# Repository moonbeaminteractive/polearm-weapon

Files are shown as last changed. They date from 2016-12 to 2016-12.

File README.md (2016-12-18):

# polearm-weapon
pole rod staff based weapon for short range area events

##Concept: 
Wand/rod is a weapon which can cast three different kinds of spells by sending sound signals to the vest. The kind of spell is visualized by the led strip on the wand. There will be deplay between each spell, and the delay time can be shortened by one of the pickups. In order to cast a spell, the player has to both swing the rod to activate it and push one of the three buttons to cast a specific type of spell. 

##Software: 

Prerequisite libraries:  <br/>
Statistic.h  <br/>
Adafruit_DotStar.h <br/>

Statistic.h: calculates the swing variance of the gyro sensor  <br/>
Adafruit_DotStar.h: controls the RGB lighting on the led strip  <br/>

The software continuously polls the 3 rod buttons (red, green, blue) to select a spell. <br/>
Also, it continuously logs ADXL accelerometer data in blocks of 100 values and calculates the variance of the samples. Using the variance instead of the raw values allows the tracking of rapid wand motions to cast a spell, no matter what the initial direction of the wand is. <br/>

When casting each spell, the DotStar LEDs light up with the respective color (blue for the blue button, red for the red button, green for the green button) to conveniently visualize which spell has been selected. Additional functionality is implemented to drive a buzzer with a frequency that depends on the spell that is casted. For the red spell, a buzzer tone with period of 100 ms is generated, for the green a tone with 200 ms period is generated, and for the blue a tone with 300 ms period is generated. <br/>

Time-sensitive functions of the code have been implemented with the millis() function to avoid blocking that the delay() function introduces. <br/>

##Usage Settings:
Current settings:<br/>
Default blockout - 30 seconds (slow recharge)<br/>
Blockout with pickup - 10 seconds (faster boosted recharge)<br/>

When a weapon booster pickup is correctly attached, the wand flashes 5 times to notify the user that it has detected and activated it. The wand glows a default yellow color when active, and whenever a spell is castable. If it is timed out, on blockout after casting a spell, all lights on the wand will switch off until it is recharged again. On casting a spell, the wand glows the same color as the spell.<br/>

To use, plug in a USB-A to USB-B connector between the wand and the vest.<br/>

##Hardware: 
1 x gyro sensor <br/>
1 x magnetic buzzer <br/>
1 x dotstar led strip <br/>
1 x arduino mini <br/>
3 x push button <br/>
1 x USB-B <br/>

Gyro sensor: detects if the rod is activated or not. Player will swing the rod to activate the weapon <br/>
Magnetic buzzer: sends sound signal to receivers installed on vests <br/>
Dotstar led strip: displays which spell just casted by the player (r, g, b) <br/>
Push button: each color of the push button (r, g, b) will send a different kind of spells <br/>
USB-B: receives serial information from the vest for shorter spell recharge delay <br/>

##Circuit and PCB Design Process: 
We started with a very simple board – an Arduino Uno, an infrared emitter, a push button and a led strip. Then we improved it by adding more components and functionalities to the board – we added a tilt sensor switch for activation, a 6 degree of freedom sensor, a Piezo buzzer for casting different spells, a nrf24l01 for Bluetooth communication, and replaced the Arduino Uno with Arduino Pro Mini. In the next phase, we replaced the 6 degree of freedom sensor with a gyro sensor and removed the tilt switch as we decided to only use swing behavior to activate the wand, which could be achieved by just using the gyro sensor. We also added three kinds of buttons, imaging the player can perform different kinds of combinations of buttons for different spells. Then we moved on to the communication with the other parts. We realized that it would work the best if we communicated with the vest directly using serial via TX/RX pins instead of Bluetooth. Finally, the design we have right now has a USB-B for serial communication with the vest, removing the Bluetooth module. 

In order to fit the PCB into the wand, we wanted to limit its width to around 3.5 cm. We decided to put the gyro sensor and buzzer at the top of the wand for more accurate measurement. The initial PCB design was just about 3.6 cm. Matt helped us to produce the final design, which used the small resistor and a more compact layout to reduce the width to 3.4 cm. It also added two transistors for 5.0 V power supply. These tiny resistors and transistors saved lots of space for PCB design.

###Circuit
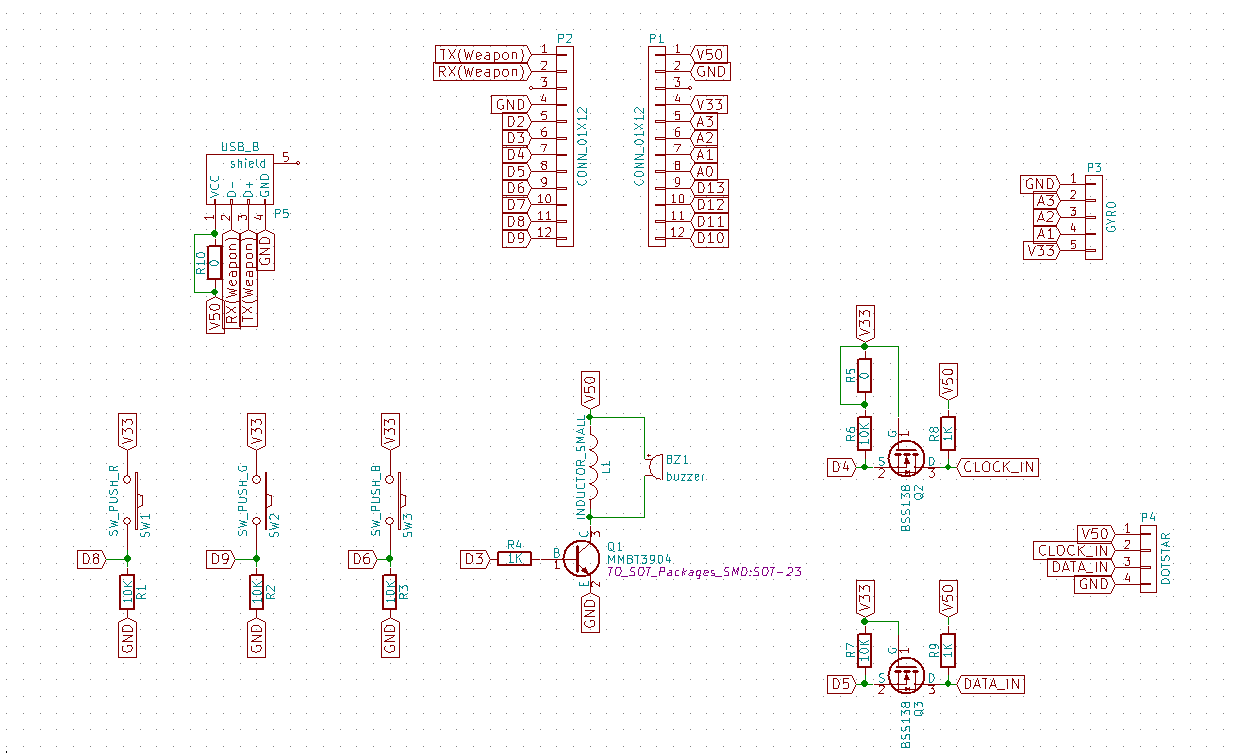
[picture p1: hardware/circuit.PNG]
Circuit
  

###PCB
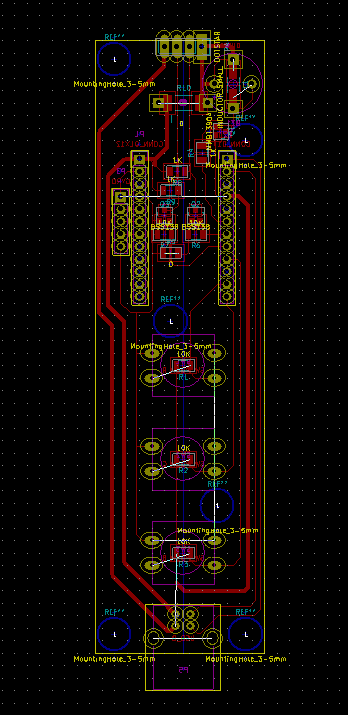
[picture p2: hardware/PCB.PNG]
PCB
  

###Fabrication Design: 
The design of weapon was in lowpoly style and we have a good rationale for the design.

The sytle of the design is futuristic overall and lowpoly design fits in the game.
Using lowpoly design, we are able to build three-dimensional objects by two dimensional materials like paper by folding them. In this way, we are able to put whatever electronics and PCB boards into it without destroying the idea of the weapon being a wand.
The design was generated by sketching, modelling and finally drawings. The tools used were Illustrator, Rhino and special thanks to Clement, whose tools helped with generating joints for the design.

As for the prototyping, We laser cut (using Epilog Mini Laser Cutter) the design using chipboard.

For the materials, we hesitated between plastic, yupo paper, chipboard as well as metal. Eventually, due to cost, the feasibility of laser cutting as well as the imagined final demonstration, we decided to have black chipboards serving as surfaces.

The output of laser film printer appears some errors because of mechanical manufacture and different settings of power and speed. The drawings were drawn in both AutoCAD and Illustrator. Dimensions in drawings were decided by both measurements and repetitive trail and error.

A challenge we encountered was to fit in the PCB boards and placing buttons, electronics at the right position, which wasted a lot of trails and time.

Deciding settings of power and speed was another challenge for us. Although each material corresponds to its suggested settings, materials produced by different manufacturers perform differently under the same setting. We kept adjusting the settings to cut through acrylic sheets but at the same time prevent it from melting and blackening. The final prototype was actually our fifth version of printing..
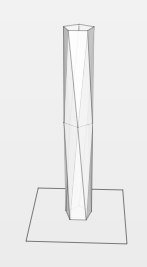
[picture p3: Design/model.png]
Design


###Paper Prototype:
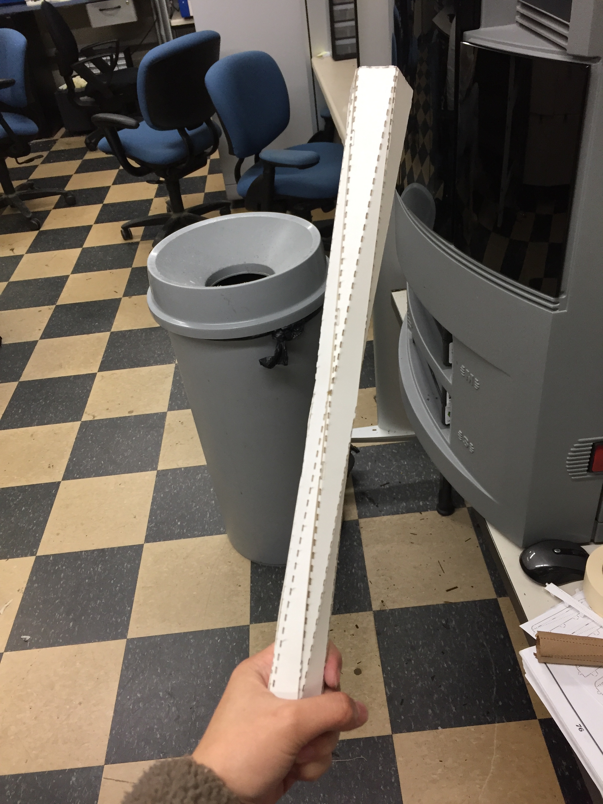
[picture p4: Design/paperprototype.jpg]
Paper
  

###Final Wand: 
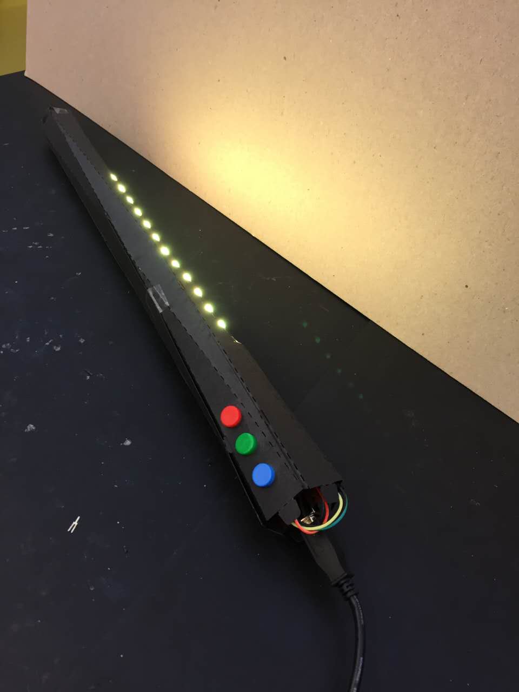
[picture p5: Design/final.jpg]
Wand


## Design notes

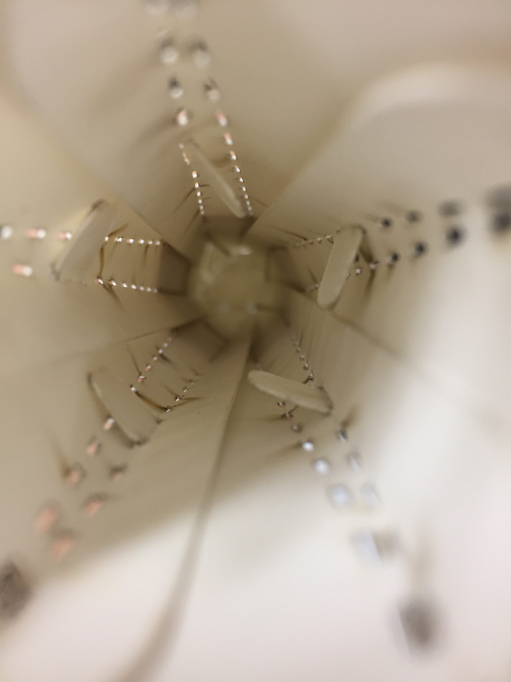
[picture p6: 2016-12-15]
Design/inside.jpg

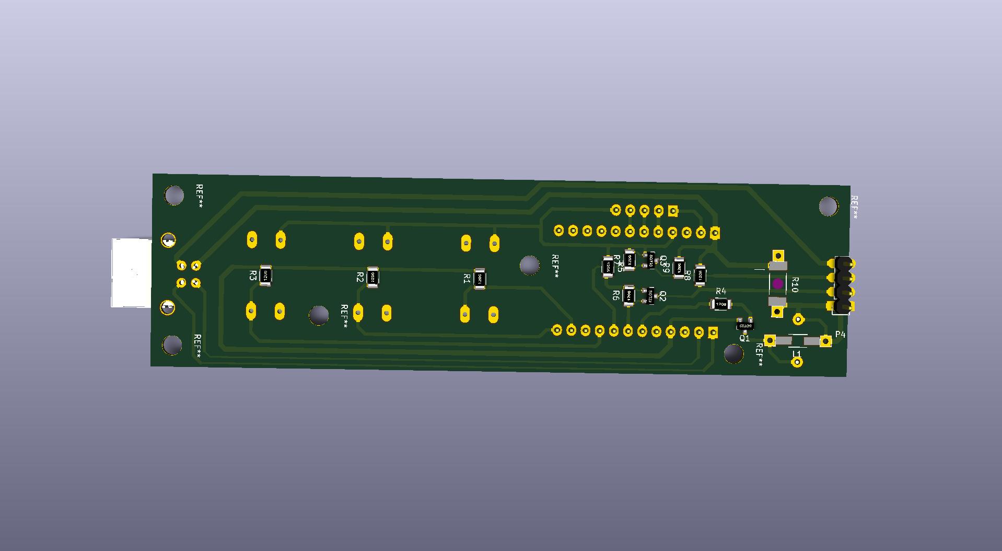
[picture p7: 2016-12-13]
hardware/rod-layout-2.jpg

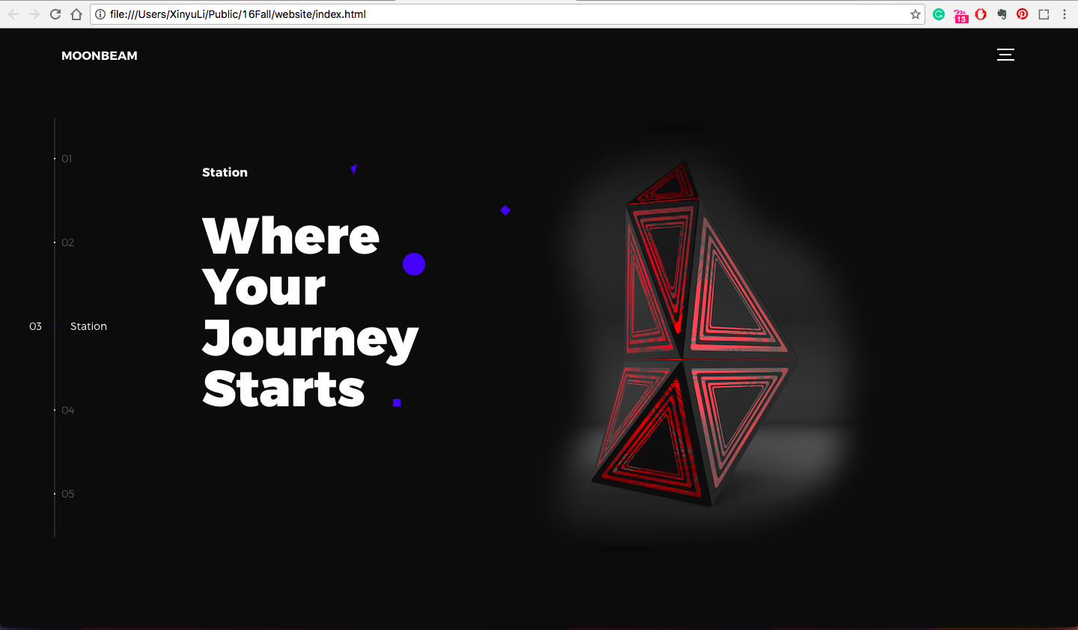
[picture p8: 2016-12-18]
Design/Screen Shot 2016-12-15 at 12.27.38 PM.png

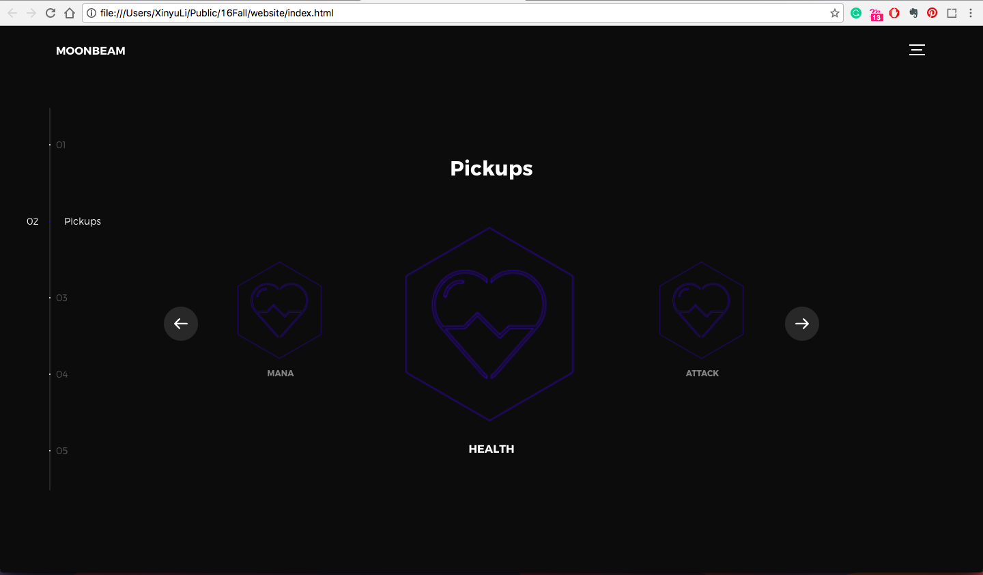
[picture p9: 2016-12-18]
Design/Screen Shot 2016-12-15 at 12.27.31 PM.png

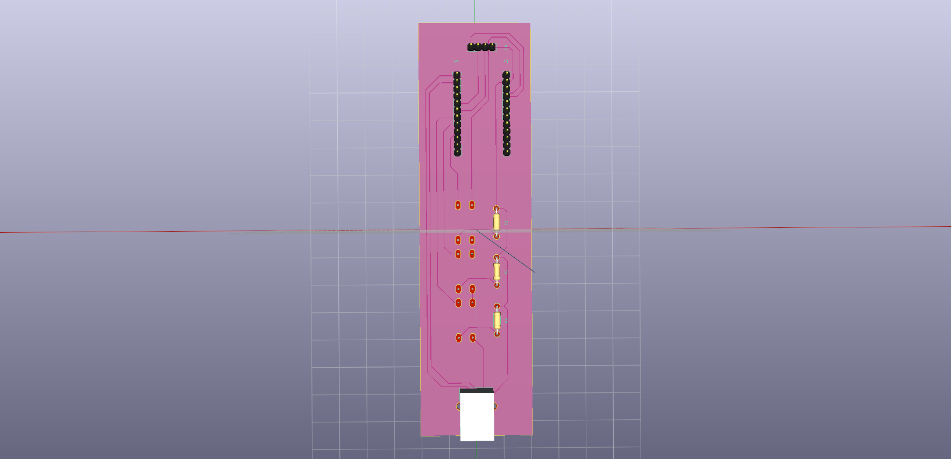
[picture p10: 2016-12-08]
hardware/rod.png

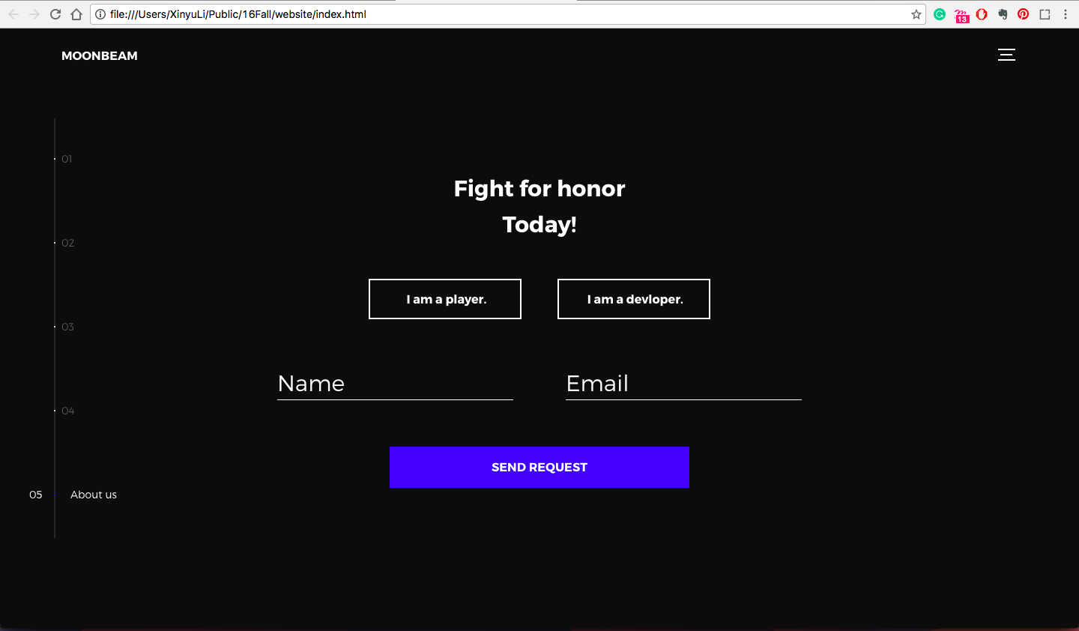
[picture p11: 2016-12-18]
Design/Screen Shot 2016-12-15 at 12.27.44 PM.png

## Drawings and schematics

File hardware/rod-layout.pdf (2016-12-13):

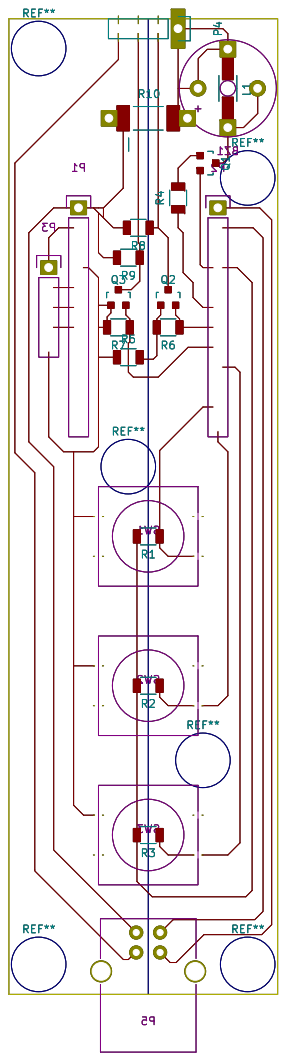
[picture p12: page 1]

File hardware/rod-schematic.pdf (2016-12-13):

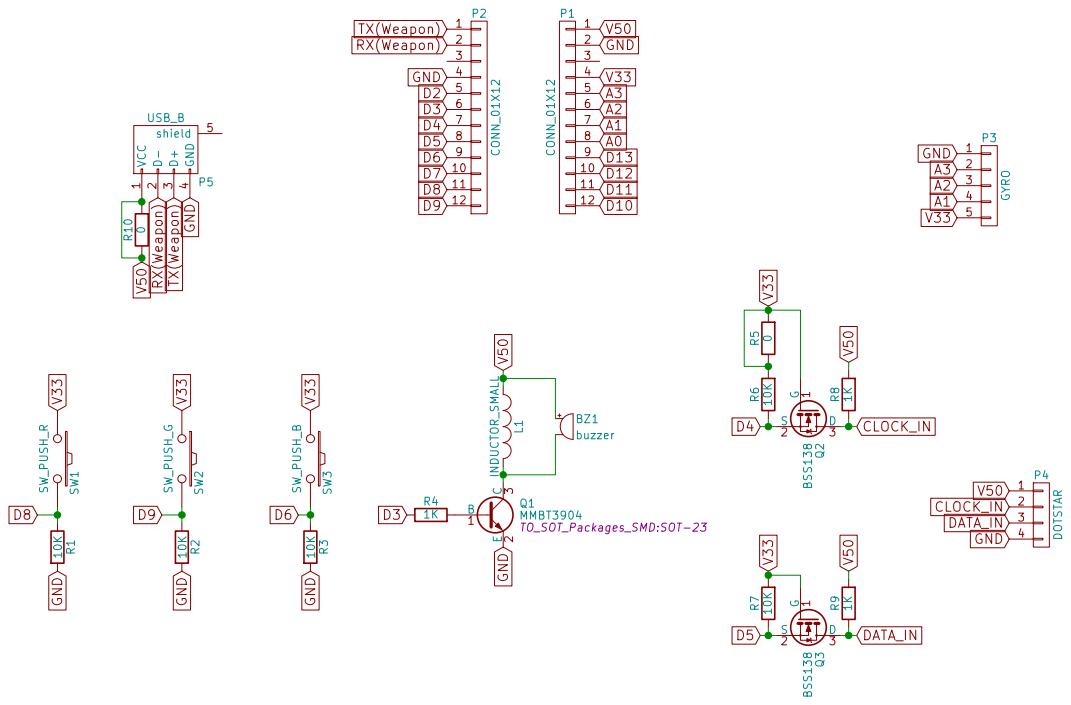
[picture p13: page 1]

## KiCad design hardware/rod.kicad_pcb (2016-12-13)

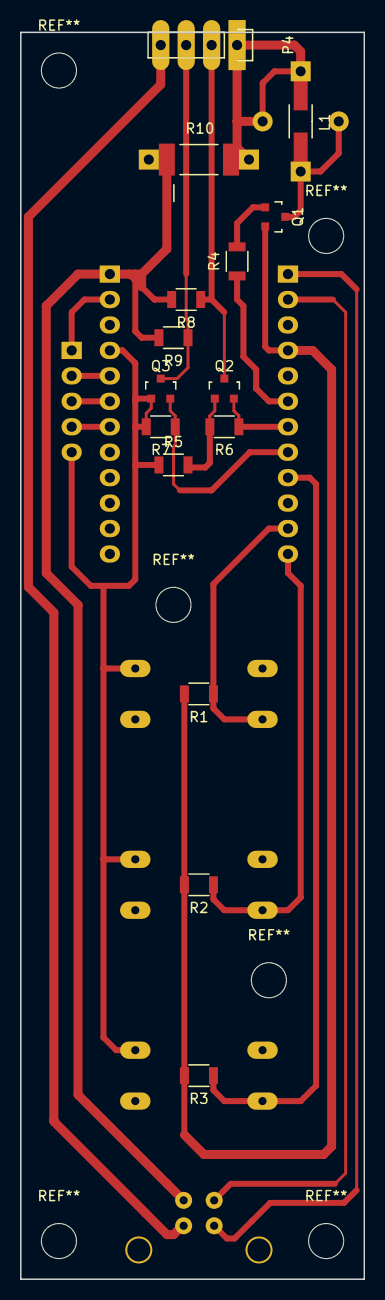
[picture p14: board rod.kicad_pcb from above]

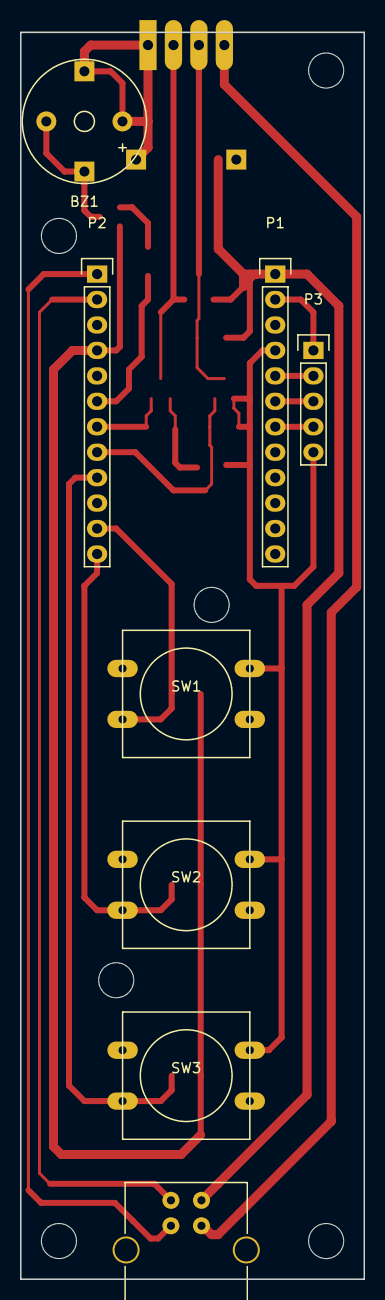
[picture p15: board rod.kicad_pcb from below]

Board: 2 copper layers, 34.3 x 124.5 mm, 23 parts (8 on the bottom side), 18 nets.

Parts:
BZ1: buzzer; Buzzer_12x9.5RM7.6
L1: INDUCTOR_SMALL; Resistor_SMD+THTuniversal_1206_RM10_HandSoldering
P1, P2: CONN_01X12; Pin_Header_Straight_1x12
P3: GYRO; Pin_Header_Straight_1x05
P4: DOTSTAR; Pin_Header_Straight_1x04
P5: USB_B
Q1: MMBT3904; SOT-23
Q2, Q3: BSS138; SOT-23
R1, R2, R3, R6, R7: 10K; R_1206
R4, R8, R9: 1K; R_1206
R5: 0; R_1206
R10: 0; Resistor_SMD+THTuniversal_2512_RM10_HandSoldering
SW1: SW_PUSH_R; SW_PUSH-12mm
SW2: SW_PUSH_G; SW_PUSH-12mm
SW3: SW_PUSH_B; SW_PUSH-12mm

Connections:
A1: P1.7, P3.4
A2: P1.6, P3.3
A3: P1.5, P3.2
CLOCK_IN: P4.2, Q2.3, R8.1
D3: P2.6, R4.1
D4: P2.7, Q2.2, R6.1
D5: P2.8, Q3.2, R7.1
D6: P2.9, R3.1, SW3.2
D8: P2.11, R1.1, SW1.2
D9: P2.12, R2.1, SW2.2
DATA_IN: P4.3, Q3.3, R9.1
GND: P1.2, P2.4, P3.1, P4.4, P5.4, Q1.2, R1.2, R2.2, R3.2
unnamed: BZ1.2, L1.2, Q1.3
unnamed: Q1.1, R4.2
RX(Weapon): P2.2, P5.2
TX(Weapon): P2.1, P5.3
V33: P1.4, P3.5, Q2.1, Q3.1, R5.1, R5.2, R6.2, R7.2, SW1.1, SW2.1, SW3.1
V50: BZ1.1, L1.1, P1.1, P4.1, P5.1, R8.2, R9.2, R10.1, R10.2

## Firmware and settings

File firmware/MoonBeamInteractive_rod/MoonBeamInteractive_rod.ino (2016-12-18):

#include <Arduino.h>
#include "Statistic.h"
#include <Adafruit_DotStar.h>
// Because conditional #includes don't work w/Arduino sketches...
#include <SPI.h>         // COMMENT OUT THIS LINE FOR GEMMA OR TRINKET



/////////// PUSHBUTTONS, LEDS, BUZZERS ///////////

const int buttonPin_green = 9;
const int buttonPin_blue = 6;
const int buttonPin_red = 8;

const int ledPin = 13;

const int buzzerPin = 3;              // buzzer positive pin


/////////// ADXL ///////////

Statistic xStats;

// these constants describe the pins. They won't change:
const int ADXL_xpin = A3;                  // x-axis of the accelerometer
const int ADXL_ypin = A2;                  // y-axis
const int ADXL_zpin = A1;                  // z-axis (only on 3-axis models)

#define ADXL_N_VALUES   100               // number of ADXL values for statistics
#define ADXL_STDEV_THRESHOLD  50          // sigma threshold for accelerometer


/////////// DOTSTAR ///////////

#define DOTSTAR_NUMPIXELS  13 // Number of LEDs in strip
#define DOTSTAR_NUMPIXELS_ON  13      // Number of LEDs to be actually used
#define DOTSTAR_NUMPIXELS_MANA  10   // Number of LEDs for Mana

#define DOTSTAR_DELAY_MS  500

#define DOTSTAR_DATAPIN    5
#define DOTSTAR_CLOCKPIN   4

Adafruit_DotStar strip = Adafruit_DotStar(
                           DOTSTAR_NUMPIXELS, DOTSTAR_DATAPIN, DOTSTAR_CLOCKPIN, DOTSTAR_BRG);
// The last parameter is optional -- this is the color data order of the
// DotStar strip, which has changed over time in different production runs.
// Your code just uses R,G,B colors, the library then reassigns as needed.
// Default is DOTSTAR_BRG, so change this if you have an earlier strip.

// Hardware SPI is a little faster, but must be wired to specific pins
// (Arduino Uno = pin 11 for data, 13 for clock, other boards are different).
//Adafruit_DotStar strip = Adafruit_DotStar(NUMPIXELS, DOTSTAR_BRG);


#define DOTSTAR_COLOR_BLUE  0x0000FF
#define DOTSTAR_COLOR_RED  0x00FF00
#define DOTSTAR_COLOR_GREEN  0xFF0000
#define DOTSTAR_COLOR_YELLOW  0xFFFF00
#define DOTSTAR_COLOR_BLANK  0x000000


// SPELLS state
#define NO_SPELL     0  //default
#define SPELL_RED    1  //indices
#define SPELL_GREEN  2
#define SPELL_BLUE   3
int spell_to_apply = 0;

//SPELL DELAY TIMER
#define DEFAULT_BLOCKOUT 30000  //30 seconds
#define BOOSTED_BLOCKOUT 10000
unsigned long set_blockout_time;    //TODO: MAKE THIS 20 OR 30 SECONDS LATER. OR MAYBE EVEN A MINUTE

boolean spell_castable = true;
unsigned long blockout_start_time = 0;

//PICKUPS
boolean pickup_present = true;
#define RECHARGE_AMMO_INDEX 0       //pre decided ammo bit from the string broadcasted by the vest
boolean prev_pickup_present = false;

void setup() {
  // initialize the serial communications:
  Serial.begin(9600);
  
 // while (!Serial) {
 //   ; // wait for serial port to connect. Needed for native USB port only
 // }

  // Recharge spells

  set_blockout_time = DEFAULT_BLOCKOUT;

  /////////// PUSHBUTTONS, LEDS, BUZZERS ///////////

  pinMode(buttonPin_green, INPUT);
  pinMode(buttonPin_blue, INPUT);
  pinMode(buttonPin_red, INPUT);

  pinMode(ledPin, OUTPUT);
  pinMode(buzzerPin, OUTPUT);

  //pinMode(testPin, OUTPUT);
  //digitalWrite(testPin, HIGH);

  /////////// ADXL ///////////
  xStats.clear(); //explicitly start clean

  /////////// DOTSTAR ///////////

#if defined(__AVR_ATtiny85__) && (F_CPU == 16000000L)
  clock_prescale_set(clock_div_1); // Enable 16 MHz on Trinket
#endif

  strip.begin(); // Initialize pins for output
  strip.show();  // Turn all LEDs off ASAP


  DOTSTAR_INIT();

}



void loop() {

 ///////// RECEIVE PICKUP FROM VEST ////////
 if (Serial.available())
    {
        String incomingString = Serial.readString();
        if (incomingString.length()>0) //this can be anything coming from the vest
        { 
               Serial.print("I received: ");
               Serial.println(incomingString);
               char bitOfInterest = incomingString[RECHARGE_AMMO_INDEX];  //change this later, maybe
               
               if(bitOfInterest=='1')
               {
                  pickup_present = true;
                  //Serial.print("bit of interest = 1");
               }
               else
               {
                  pickup_present = false;
                  //Serial.print("bit of interest = 0");
               }
         }
        setBlockoutTime(pickup_present);
  }


  /////////// PUSHBUTTONS ///////////
  
  int button_reading_green = digitalRead(buttonPin_green);
  int button_reading_blue = digitalRead(buttonPin_blue);
  int button_reading_red = digitalRead(buttonPin_red);


  if (button_reading_red) {
    spell_to_apply = SPELL_RED;
    //tone(5,10000);
  }
  else if (button_reading_green) {
    spell_to_apply = SPELL_GREEN;
    //tone(5,5000);
  }
  else if (button_reading_blue) {
    spell_to_apply = SPELL_BLUE;
    //tone(5,50000);
  }
  else
  {
    spell_to_apply = NO_SPELL;
    //noTone(5);
  }


  /////////// ADXL ///////////

  int xval, yval, zval, stdev;

  for (int i = 0; i < ADXL_N_VALUES; ++i) {
    xval = analogRead(ADXL_xpin);
    yval = analogRead(ADXL_ypin);
    zval = analogRead(ADXL_zpin);

    xStats.add(xval);

  }

  stdev = xStats.unbiased_stdev();
  //Serial.println(stdev);            //UNCOMMENT FOR SEEING MOTION ON SERIAL PLOTTER!

  xStats.clear();

  ///////////Setting delay timer for each spell//////////////
  if(millis()-blockout_start_time > set_blockout_time)
  {
      spell_castable = true;
  }
  

  /////////// BUZZER ///////////

  //put all this inside an "if spell is castable".
    if(spell_castable)
    {
        if (stdev > ADXL_STDEV_THRESHOLD && spell_to_apply != NO_SPELL) // if wand was moved rapidly and some spell button is pressed
        {   
            castSpell(spell_to_apply);
            spell_castable = false;
            blockout_start_time = millis();

        }

        else{
            for (int i = 0; i < DOTSTAR_NUMPIXELS; ++i) {
              strip.setPixelColor(i, DOTSTAR_COLOR_YELLOW); // yellow
              }
            strip.show();
        }
    
     }

     else
     {
        for (int i = 0; i < DOTSTAR_NUMPIXELS; ++i) {
        strip.setPixelColor(i, DOTSTAR_COLOR_BLANK);
          }

        strip.show();
     }
   

}




////////// function for updating blockout times, based on pickup information //////////
void setBlockoutTime(boolean pickup)
{
    if(pickup)
    {
        set_blockout_time = BOOSTED_BLOCKOUT;
        //show booster
        //flash 5 times!
        if(!prev_pickup_present)
        {
              for(int j=0; j<5; j++)
              {
                  for (int i = 0; i < DOTSTAR_NUMPIXELS; ++i) {
                    strip.setPixelColor(i, DOTSTAR_COLOR_BLANK); // Dotstar: red
                    }
                  strip.show();
                  delay(200);
                  for (int i = 0; i < DOTSTAR_NUMPIXELS; ++i) {
                    strip.setPixelColor(i, DOTSTAR_COLOR_YELLOW); // Dotstar: red
                    }
                  strip.show();
                  delay(200);
              }
        }
    }
    else
    {
        set_blockout_time = DEFAULT_BLOCKOUT;
        
    }
    prev_pickup_present = pickup;
}




/////////// BUZZER ///////////
void buzz(int spell) {
  int ms = 100*spell;
  if(spell == SPELL_RED)
  {
     for (int i = 0; i < DOTSTAR_NUMPIXELS; ++i) {
              strip.setPixelColor(i, DOTSTAR_COLOR_RED); // Dotstar: red
            }
            strip.show();  
  }
  else if(spell == SPELL_GREEN)
  {
    for (int i = 0; i < DOTSTAR_NUMPIXELS; ++i) {
              strip.setPixelColor(i, DOTSTAR_COLOR_GREEN); // Dotstar: red
            }
            strip.show();
  }
  else if(spell==SPELL_BLUE)
  {
    for (int i = 0; i < DOTSTAR_NUMPIXELS; ++i) {
              strip.setPixelColor(i, DOTSTAR_COLOR_BLUE); // Dotstar: red
            }
            strip.show();
  }
  digitalWrite(buzzerPin, HIGH);
  delay(ms);
  digitalWrite(buzzerPin, LOW);
  delay(ms);
}

/////////CAST SPELL//////

void castSpell(int req_spell_to_apply)    // apply spell
{
   for (int i = 0; i < 4; ++i) 
   {       
      buzz(req_spell_to_apply);  // red spell buzzer period: 100ms, green spell buzzer period: 200ms, blue spell buzzer period
      
   }

}




/////////// DOTSTAR ///////////
void DOTSTAR_INIT() {
  for (int i = 0; i < DOTSTAR_NUMPIXELS_MANA; ++i) {
    strip.setPixelColor(i, DOTSTAR_COLOR_YELLOW);
    strip.show();
    delay(100);
  }
  for (int i = DOTSTAR_NUMPIXELS_MANA; i < DOTSTAR_NUMPIXELS; ++i) {
    strip.setPixelColor(i, DOTSTAR_COLOR_BLANK);
  }

  strip.show();

}

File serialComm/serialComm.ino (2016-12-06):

#include <SoftwareSerial.h>

SoftwareSerial mySerial(8, 9);

const int buttonRPin = 2;     // the number of the pushbutton pin
const int buttonGPin = 3;     // the number of the pushbutton pin
const int buttonBPin = 4;     // the number of the pushbutton pin
 
// variables will change:
int buttonRState = 0;   
int buttonGState = 0;   
int buttonBState = 0;   
char RText = "r";
char GText = "g";
char BText = "b";
int incomingByte = 0;

void setup()
{
  Serial.begin(9600);
  while (!Serial) {
    ; // wait for serial port to connect. Needed for native USB port only
  }
  pinMode(buttonPin, INPUT);
 // Serial.println("Connected!");
  // set the data rate for the SoftwareSerial port
  mySerial.begin(4800);
  mySerial.println("Serial Connected.");

}

void loop()
{
  buttonRState = digitalRead(buttonRPin);
  buttonGState = digitalRead(buttonGPin);
  buttonBState = digitalRead(buttonBPin);

  //receive data
  if (mySerial.available()){
    incomingByte = mySerial.read();
    mySerial.print("I received: ");
    mySerial.println(incomingByte);
  }

  //send data
  if (buttonRState == HIGH) {
    mySerial.write(RText);
    delay(50);
  }
   if (buttonGState == HIGH) {
    mySerial.write(GText);
    delay(50);
  }
   if (buttonBState == HIGH) {
    mySerial.write(BText);
    delay(50);
  }
}

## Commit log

2016-12-02 send/receive signal
    send r/g/b color text to another arduino on clicking r/g/b button
2016-12-06 add current schematics and pcb
    [_saved_rod.sch, rod.kicad_pcb, rod.sch]
2016-12-08 fixed DotStar color issue
    [MoonBeamInteractive_rod.ino]
2016-12-08 Updated PCB
    [rod.kicad_pcb, rod.sch]
2016-12-08 "Updated PCB"
    [rod.kicad_pcb]
2016-12-08 bak file created
    [rod.kicad_pcb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]
2016-12-11 3.6cm width pcb
    [rod.kicad_pcb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]
2016-12-13 updated semi-final version of rod pcb schematics and layout
    [rod.kicad_pcb, rod.sch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]
